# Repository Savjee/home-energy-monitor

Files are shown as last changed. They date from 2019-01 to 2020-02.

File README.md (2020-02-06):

<p align="center">
    <a href="https://github.com/Savjee/home-energy-monitor" rel="noopener">
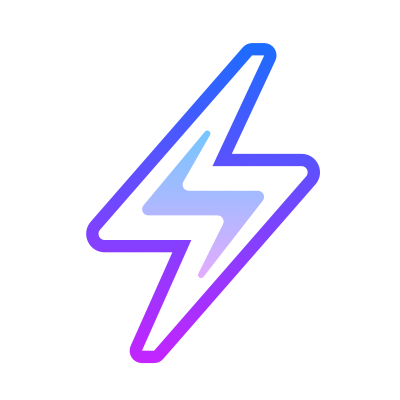
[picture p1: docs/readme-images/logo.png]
Home Energy Monitor
        
    </a>
</p>

<h3 align="center">Home Energy Monitor (v2)</h3>

<div align="center">





**⚠️ This is a work in progress. By no means is this production ready.**
</div>

---

ESP32-based Home Energy Monitor: monitors electricity consumption of your entire house with a single CT sensor.

## Structure

This project consists out of multiple components:

| Folder | Description | Build status | 
| --- | --- | --- |
| `src-app` | Mobile app (Ionic)  | n/a |
| `src-aws` | Serverless AWS backend + GraphQL API |  |
| `src-esp32` | Firmware for the ESP32 (measuring device) |  |

(TODO: add instructions on how to deploy all of this. 😅)

## Video explanation

<div align="center">

IMAGE ALT TEXT HERE (https://www.youtube.com/watch?v=ah3ezprtgmc)

*[https://www.youtube.com/watch?v=ah3ezprtgmc](https://www.youtube.com/watch?v=ah3ezprtgmc)*
</div>

Read my blog post for more instructions: [https://savjee.be/2019/07/Home-Energy-Monitor-ESP32-CT-Sensor-Emonlib/](https://savjee.be/2019/07/Home-Energy-Monitor-ESP32-CT-Sensor-Emonlib/)

## Cloud Architecture

This is the cloud architecture that powers the energy meter and the app:

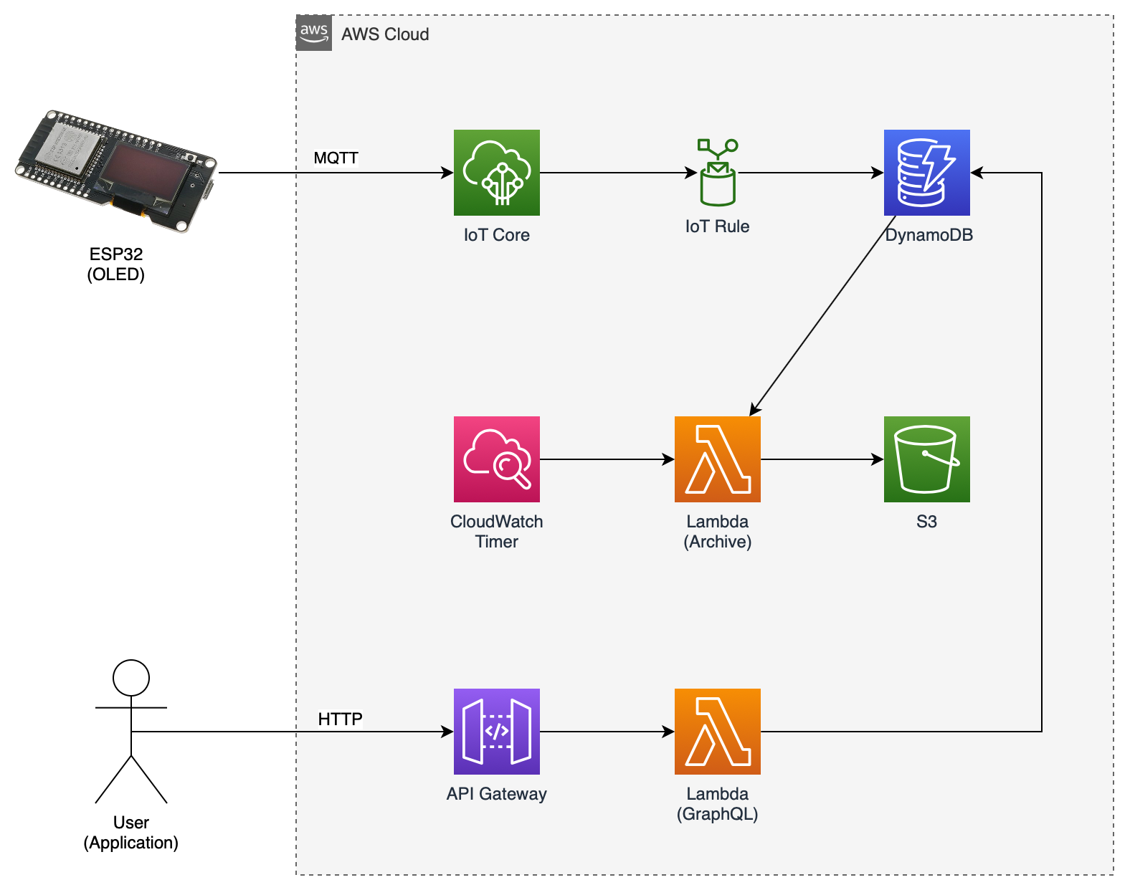
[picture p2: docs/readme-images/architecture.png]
AWS Cloud Architecture


In a nutshell:
* The ESP32 has a MQTT connection with AWS IoT Core
* Every 30 seconds, 30 measurements are sent to AWS
* These measurements are stored in DynamoDB (IoT Rule)
* Once a day, all readings from the previous day are archived to S3
* A GraphQL API (hosted on Lambda) exposes the data stored in DynamoDB

## Screenshots

Web dashboard, built on top of the GraphQL API:

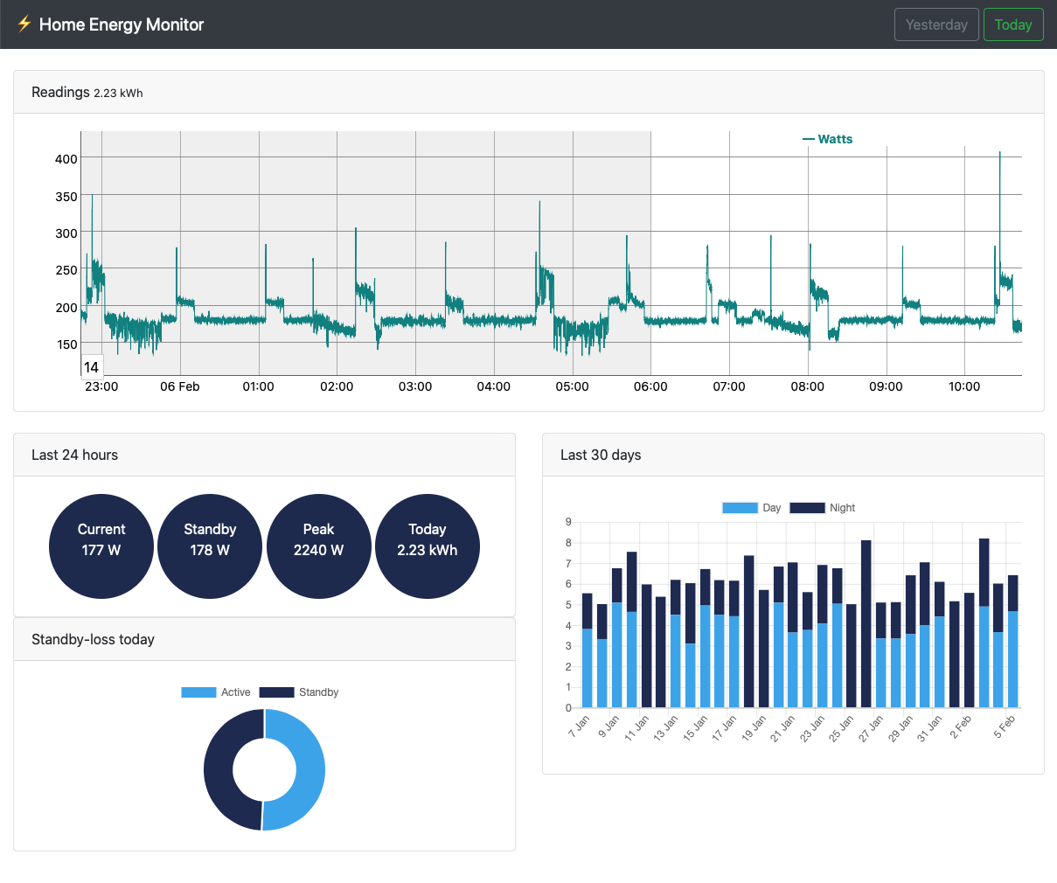
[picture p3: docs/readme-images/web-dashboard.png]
Screenshot Web Dashboard


What is displayed on the ESP32 OLED display:

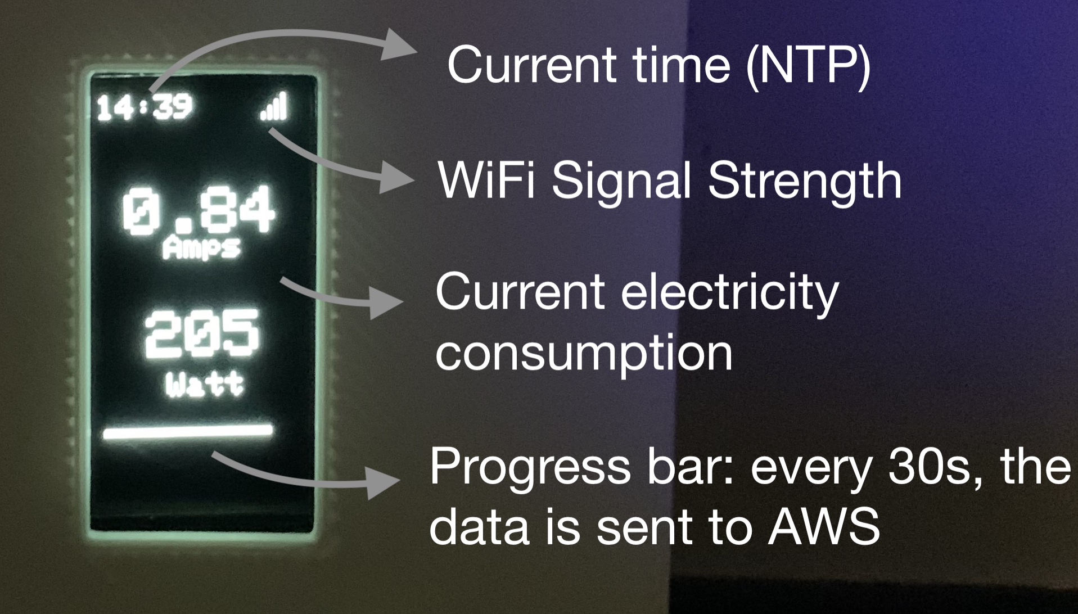
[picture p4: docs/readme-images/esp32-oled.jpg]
Screenshot ESP32 OLED


## DIY Requirements

To build your own Energy Monitor you need the following hardware:

* ESP32
* CT sensor: YHDC SCT-013-030 (30A/1V)
* 10µF capacitor
* 2 resistors (between 10k-470kΩ)

Other requirements:
* AWS Account (Should be able to run in free-tier)
* Install [PlatformIO](https://platformio.org) on your system
* Drivers for your ESP32 board

Read my blog post for more instructions: [https://savjee.be/2019/07/Home-Energy-Monitor-ESP32-CT-Sensor-Emonlib/](https://savjee.be/2019/07/Home-Energy-Monitor-ESP32-CT-Sensor-Emonlib/)

## Contribute

I'm happy to merge in any pull requests. Also feel free to report bugs or feature requests.

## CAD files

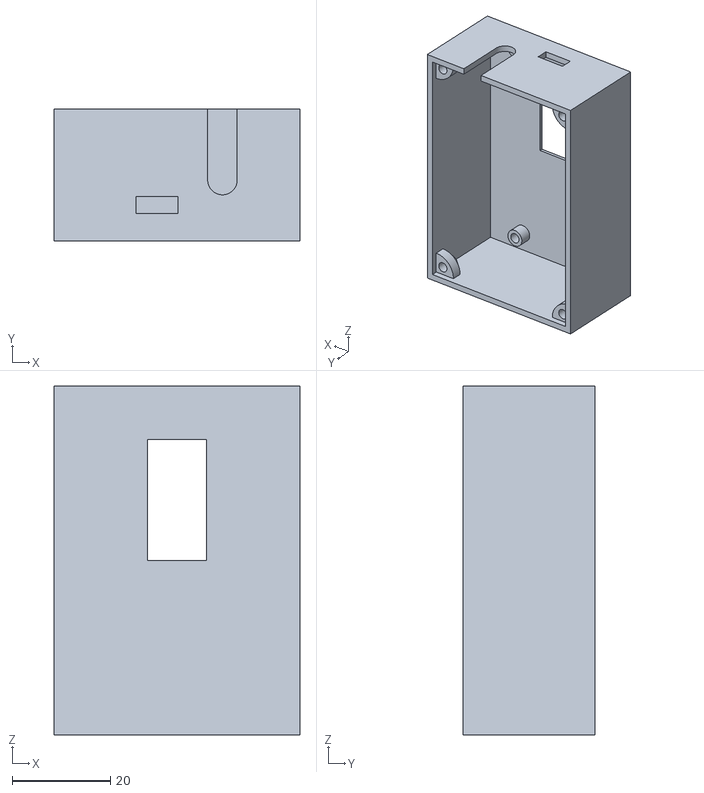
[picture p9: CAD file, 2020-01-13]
3D-designs/01 - Case.stl
50.0 x 26.9 x 71.0

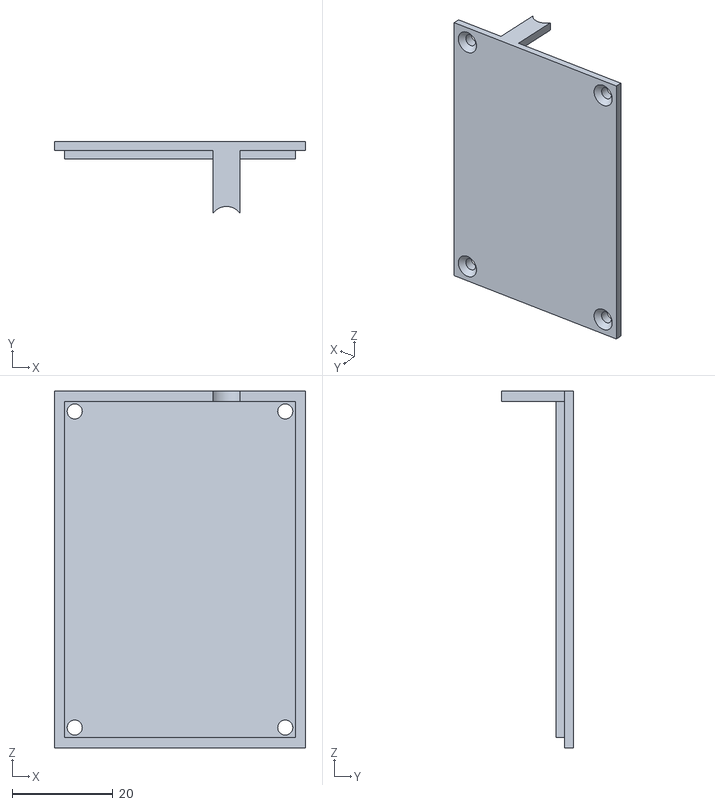
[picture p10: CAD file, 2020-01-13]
3D-designs/02 - Top lid.stl
50.0 x 14.3 x 71.0

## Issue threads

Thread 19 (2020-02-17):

Rebooting on wifi connection screen

CatalanCaptain, 2020-02-17:
After successfully download the firmware on the board, it stucks on wifi connecting page and then reboots forever every second or less.
After running exception decoder, I found that it was due to line #47 on wifi-connection.h task, that shows the status and the IP adress.
After commenting this line everything works fine and pass to the next page, showing power consumption.

Thanks for your awesome work!

Savjee, 2020-02-18:
Interesting.

Could you tell me what versions of PlatformIO & ESP32 framework you're using?

Also: could you test to see if it helps to replace that line with a more simple version (without the F() macro and without my debug serial):

```cpp
Serial.println("[WIFI] Connected: " + WiFi.localIP());
```

CatalanCaptain, 2020-02-18:
Actually running 4.2.0 on platformIO and 1.11.2 on ESP32.
Replacing the line without F() didn't worked. Also, setting `#define DEBUG true` to false, didn't worked either.

Savjee, 2020-02-21:
Really weird, I'm running the exact same versions as you.
For now, I will keep this issue open and see if others are experiencing the same issue.

Have you looked into this in more detail? Any other bug reports mentioning issues with `localIP()` ?

CatalanCaptain, 2020-02-21:
Here is the complete exception decoder output, if you can see anything that I can't

`PC: 0x400014dc
EXCVADDR: 0xce41cbd3

Decoding stack results
0x400d5f59: Print::write(char const*) at C:\Users\My_user\.platformio\packages\framework-arduinoespressif32\cores\esp32/Print.h line 66
0x400d5fcd: Print::println(char const*) at C:\Users\My_user\.platformio\packages\framework-arduinoespressif32\cores\esp32\Print.cpp line 89
0x400d1a76: keepWiFiAlive(void*) at src\tasks/wifi-connection.h line 47
0x400896f9: vPortTaskWrapper at /home/runner/work/esp32-arduino-lib-builder/esp32-arduino-lib-builder/esp-idf/components/freertos/port.c line 143
`

freeesty, 2020-03-15:
having the same issue, 4.2.1 on platformIO and 1.11.2 on ESP32.

Savjee, 2020-03-15:
@freeesty Did it help to remove this line?

`Serial.println("[WIFI] Connected: " + WiFi.localIP());`

freeesty, 2020-03-15:
yes

Savjee, 2020-04-02:
What happens if you replace it with

```
Serial.print("[WIFI] Connected: ");
Serial.println(WiFi.localIP());
```

Really puzzled as to why this gives issues for some, but not for others.

henklietaert, 2020-04-27:
I have the same issue, printing just some words resolves the issue:
` serial_println("Some words");`

henklietaert, 2020-04-27:
The two lines you posted do work for me btw.

TiSiAi, 2020-05-12:
Hello
the macro F(...) include the wifi.localIP() function

replace
serial_println(F("[WIFI] Connected: " + WiFi.localIP()));

with
serial_print(F("[WIFI] Connected: "));
serial_println(WiFi.localIP());

Savjee, 2020-05-28:
Good catch @TiSiAi
I updated the code to fix that ;) https://github.com/Savjee/home-energy-monitor/commit/5c14406d0bf7cac692ed733589ca177845626ab7

Closed 2020-05-28.

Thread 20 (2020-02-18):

Non-zero readings

CatalanCaptain, 2020-02-18:
After setting all up if I plug the CT sensor but with no wire through it, I have a non-zero readings, about 0,1A.
I suspect that this is caused by the difference on the voltage divider resistors, that gives a reference voltage something different than 3,3V/2=1.65V.
It would be interesting to implement some kind of calibration routine to add an offset and get more accurate readings.
Also, when connecting a (theorically) 2000W air heater, readings go around 1800W-1900W. But in this case, I don't know if it's related with the same issue.

Thanks for your time and dedication @Savjee

Savjee, 2020-02-21:
For calibration, you can try playing with `emon1.current` in the main file: https://github.com/Savjee/home-energy-monitor/blob/master/src-esp32/src/main.cpp#L56

The second parameter is a calibration value. More details about it here:
https://learn.openenergymonitor.org/electricity-monitoring/ctac/ct-and-ac-power-adaptor-installation-and-calibration-theory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

As for a calibration routine: that's an interesting idea, but it would require some additional hardware. A button or so to trigger it.

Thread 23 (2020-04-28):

Three phase version

aleonnet, 2020-04-28:
Hi @Savjee great job!
It would be very good if you co

uld include a three phase version. I mean read the current and voltage for the three phases. These would open the possibility for several other applications and house sizes!

Does the EmonLib-esp32 support the three phase calculations?

By the way I will open source my small board to adapt current from the sct-013-000.
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

Savjee, 2020-05-01:
A 3-phase system requires 3 separate CT sensors. This should be easy to achieve because the ESP32 has enough ADC inputs. The only thing required is enough input pins for the sensors ;)

The library doesn't need to be changed. You can create 3 instances of it and have them work together.

Cool! What software are you using to design that PCB? I started mine on EasyEDA but didn't finish it yet. Hard to find components like headphones jacks with correct footprints for EasyEDA. How are you tackling this?

aleonnet, 2020-05-01:
I'm afraid the power factor for each phase would not be calculated correctly, by simply measuring the current without its corresponding voltage. Maybe this can be adjusted by software. What do you think?
I'm using EasyEDA as well and I its really not easy :) to find some good components' footprints. However you can use a pachymeter to check your actual components. For example, I had to adjust the hole size of the stereo jack with it, note that it's larger.

Savjee, 2020-05-09:
Indeed, this is my current problem. I need to add support for a voltage sensor as well. Then the setup would work:

- 3 CT clamps for measuring current
- 1 voltage sensor

Now you can:
- Measure voltage
- Measure current with 3 emonlib instances (while using the actual voltage measurement)

That should give fairly good results. From what I read on OpenEnergyMonitor, it requires an AC-AC power adapter: https://learn.openenergymonitor.org/electricity-monitoring/voltage-sensing/measuring-voltage-with-an-acac-power-adapter

Glad I'm not the only one struggling with EasyEDA. Problem is that I don't have all my components yet. Still waiting on a few from AliEpress...

gieljnssns, 2020-11-30:
@Savjee Any updates on this?

Savjee, 2020-12-02:
I've abandoned the idea of creating a custom PCB. Maybe @aleonnet has finished his?

gieljnssns, 2020-12-02:
@Savjee
I mean the three phase version…
And the support for the voltage sensor.

Savjee, 2020-12-03:
No updates on those fronts, unfortunately.

gieljnssns, 2020-12-17:
@Savjee
> A 3-phase system requires 3 separate CT sensors. This should be easy to achieve because the ESP32 has enough ADC inputs. The only thing required is enough input pins for the sensors ;)

What do you mean with this?
Which pins can be used for ADC? What numbering do I have to use?
https://esp32.com/viewtopic.php?t=13145
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

JamesLeonDufour, 2022-10-11:
I'll be interested to follow up on that one. Here is a good article . http://www.technik-fan.de/index.php/Open_Energy_Monitor_mit_dem_ESP32
That would require an esp 32 not 8266 right ?

Savjee, 2022-10-11:
Yes, the ESP8266 only has 1 ADC channel and you would need 3.
There are two options:
1. Switch to an ESP32 which has 18 channels in total (8 + 10)
2. Use the ESP8266 with an external ADC.

Regardless of which option you choose, an external ADC will always give you better accuracy compared to the built-in ADC.

JamesLeonDufour, 2022-10-11:
Hi Savjee,

Thanks for taking the time to answer, I have been digging quiet a lot on CT clamp and did my first iteration.

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

This is based on your project. Luckily I ordered a SCT-013-030 30a 1v that I assume you are using in your project and if I understand correctly after my reserach doesnt need a burden resistor and seem to make the job a lot easier for everyone (instead of output a ma) ?

So i connected the whole thing, added an Oled screen as you can see and was going to work on the IOT platform, MQTT etc later to transmit data.

Just when I wanted to install it, I realised that I had 3 phases in my house (Belguim), so I continued my digging.

Using the ESP32 option(I have one), the easy way I found is basically replicate the same approach like this example and yours x3. Pretty straight forward. http://www.technik-fan.de/index.php/Open_Energy_Monitor_mit_dem_ESP32.

Other option you are mentionning would be connecting an ADS1115 ? to 3 SCT clamp. But the 0-1V model like the one i have or should i switch back to a 000 series (in ma).

You are mentionning the external ADC (eg: ads1115) would be more accurate, but would I still be able to read each phases independently ? (Could be interesting to monitor which part of the house and plugs consume more).

There is this nice pieces of circuitery as well 4 channel, https://www.mottramlabs.com/esp_products.html but seems a bit of lot of complication with the 2 options listed before.

Lets me know which approach you would follow first ? the easiest ?  ( i assume the ESP8266 + ADS1115 + SCT013-030)

Thanks in advance, this is a very debatted project and seems to be a lot of confusion around the SCT CT clamp different model and the whole interfacing and not really clear project for 3 phases at least.

Best

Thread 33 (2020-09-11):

Standby power consumption

sid548, 2020-09-11:
Hello,
I am going through the project but one thing still I am not able to understand is about the standby power consumption (Always -ON)
. What is the purpose of calculating it and how is it being calculated ?

It would be great if you can give me a hint about that .

Thanks

Savjee, 2020-09-11:
Standby power is the minimum amount of power that your house consumes with appliances that are always on. That's the consumption of: fridges, freezers, standby devices, always plugged-in chargers, etc...

It's being calculated here: https://github.com/Savjee/home-energy-monitor/blob/master/src-aws/functions/graphql/resolvers/stats.js#L20

It basically is the "mode" of the dataset. -> The lowest, most frequently seen value in the set.
That's probably not the correct way of calculating it, but it's close enough.

Hope that helps.

sid548, 2020-09-11:
Thanks a lot

Savjee, 2020-09-11:
Going to close this issue now. But let me know if you have additional questions ;)

Closed 2020-09-11.

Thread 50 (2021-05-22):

Strange behaviour: ESP32 serial monitor shows MQTT msg sent but AWS IOT never receives the same

adukale, 2021-05-22:
Hi
Finally decided to ditch the esp8266 and move to esp32. Made necessory modifications and uploaded code on ESP32.
AWS IOT registers the device, esp32 shows MQTT msg sent in serial monitor but the message is never recived on AWS iot.
No rules executed, nothing. Tried changing the rule, also tried the test menu from AWS IOT to subscribe to "#" i.e. all topics, here also the result is same. No message received.
Also, in thing's activity menu I can see the device was connected but in next 10 seconds the device was disconnecting, this behavior was consistant.

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

The serial monitor shows: AWS publish then AWS Connecting. Is this normal?
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

Savjee, 2021-05-23:
It's not normal that it has to reconnect after sending a message. Looks like a permission issue. When the ESP32's certificate is not allowed to publish to a certain topic, the broker will disconnect you.

Try enabling IoT Core logging and check CloudWatch for additional details:
https://docs.aws.amazon.com/iot/latest/developerguide/configure-logging.html#configure-logging-console

adukale, 2021-05-23:
@Savjee Thank you for the quick response. Checking with this.
Just a query, how should be the certificate & keys in certificates directory? As it is or do I need to enclose the lines in " - " \?

Savjee, 2021-05-23:
As it is, no changes needed.

adukale, 2021-05-23:
@Savjee Thank you for pointing me in the right direction.
Don't know what was the exact issue but I have managed to get the esp32 up and running after fiddling with policies & certificates.
Thank You for the Awesome Project.

Savjee, 2021-05-24:
Nice! AWS IoT Policies are indeed a nightmare to configure correctly. Hard to debug as well.

Closed 2021-05-23.

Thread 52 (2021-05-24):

Readings Screen: The time shown in chart is not in the local timezone.

adukale, 2021-05-24:
The time series in chart x axis is not in the user's timezone / reading's timezone.
Not exactly sure how to fix this because the timestamp returned with readings has correct time but on chart this reflects that the readings are approx 5-5.5 hours before.
Ex: Following screenshot show time & readings from 5AM to 10AM but actually the readings are of time between 11 AM to 4:30 PM.
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

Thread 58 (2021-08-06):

Entity not available for a long time when restarting homeassistant

Pigi-102, 2021-08-06:
When I restart homeassistant for, say , a configuration change or whatever reason the sensor remain in entity not available for quite a long time.
I use mosquitto as broker and all my other sensor ( not "autoconfigured" ) start sending data to broker and get sent to HASS as soon as the HASS itself is up and running.
The only one that remains in "Entity not available" is your ( wonderful ) sensor.
From the mosquitto log I can see that my ESP32 send the message :
1628280703: Received PUBLISH from IoTEnMon (d0, q0, r0, m0, 'homeassistant/sensor/IoTEnMon/state', ... (14 bytes))
but being that HASS does not have a configuration for it, mosqutto don't forward it to HASS.
After some time ( 10 minutes or more ) the ESP32 send the config message:
1628281285: Received PUBLISH from IoTEnMon (d0, q0, r0, m0, 'homeassistant/sensor/IoTEnMon/config', ... (318 bytes))
and from this moment everything works as expected.
Is it possible to have some config item to choice between autoconfig and manually config ?

Savjee, 2021-08-16:
Normally we send a discovery message to Home Assistant every 15 minutes. So it should only take 15minutes at most to get your sensor back in HA.

That FreeRTOS task is defined here:
https://github.com/Savjee/home-energy-monitor/blob/70fd234b305f2d3f8040fb9a9ef743cf9b9b6e74/src-esp32/src/tasks/mqtt-home-assistant.h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

You could run this task more frequently, or trigger it when the MQTT connection is first established.

Not sure if there's another way around this. Maybe define an empty template sensor in HA? Not sure if MQTT could then update it though.

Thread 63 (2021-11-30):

Add multiple sensors

KillahB33, 2021-11-30:
Is this possible to use one of the other inputs on the ESP32 to add another sensor?
I am going to set this up in my main panel and wanted to track a few other things.

Savjee, 2021-12-01:
Yes that's possible by creating more instances of Emonlib.
Unfortunately this is not something I can work on. Happy to accept pull requests though ;)

KillahB33, 2021-12-01:
Deal, I'll see if I can make that happen. Thanks for pointing me in the right direction!

Closed 2021-12-01.

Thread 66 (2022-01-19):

Direct CT Connection

JuandreG, 2022-01-19:
Hello.

Is it possible to connect the SCT013 directly to the ESP32 board and measure amps? You mention that your initial thought was to cut it off and connect the wires directly to the ESP32 board, I would like to do this but I don't know where to connect the wires on the board.

If you could please guide me in connecting these wires on the board directly it would be greatly appreciated.

Regards and awesome project.

Savjee, 2022-01-20:
Hi,

Yes you can connect it directly to the ESP32. It's the exact same wiring. Same pins as you would use for the headphone jack.

Closed 2022-01-20.

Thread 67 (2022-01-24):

Will this work with your code

steveuk23, 2022-01-24:
Hi I love your project and am wondering do you think this ready made board will work with your code.
I prefer the idea of WiFi & MQTT reconnecting that your have on yours.
This guy makes boards on eBay but recommends his code.
Thanks
[https://www.ebay.co.uk/itm/ESP8266-Mains-Current-Sensor-Wemos-Current-transformer-SCT013-100A-50mA-/133077015640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](Ebay)

Savjee, 2022-01-28:
It seems compatible yes. The only things that might change are pin numbers.

Closed 2022-01-28.

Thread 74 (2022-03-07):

Very interresting but can't understand the wiring !

davidmarli, 2022-03-07:
Hi, I'm very interristing on building it, but I don't understand the wiring process ...

Would it be possible to have a complete scheme with resistors, sct-013 plug ... ?

On the blog, it's just 2 pictures and I see nothing ...

Thank you fo your help.

Savjee, 2022-03-08:
The scheme is shown on the V1 blog post:
https://savjee.be/2019/07/Home-Energy-Monitor-ESP32-CT-Sensor-Emonlib/

Closed 2022-03-08.

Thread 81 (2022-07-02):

Getting more Irms decimal points

Ganeshgng, 2022-07-02:
Hi I am Trying to upload sensor data, current and voltage to mysql database. But I am struck. where
Irms value updating only two decimal places e.g X.XX, But I need X.XXXX, How to do it? I tried
1. defining double Irms = emon.Irms/1.0000;
But when I try serial print & lcd print I can get the precision
e.g Serial.print(emon.Irms, 5);

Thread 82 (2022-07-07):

How is the board powered?

vijaygill, 2022-07-07:
Hi,

Interesting project! Thanks for that.

A quick question - how is the voard powered? I don't see any mention of power-supply for ESP32 itself.

Thanks.

Savjee, 2022-07-07:
I used the microUSB connection on my ESP32. Connected to my modem which was nearby.

Closed 2022-07-07.

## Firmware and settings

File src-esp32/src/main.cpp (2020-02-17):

#include <Arduino.h>
#include "EmonLib.h"
#include "WiFi.h"
#include <driver/adc.h>
#include "config/config.h"
#include "config/enums.h"
#include <Wire.h>
#include <Adafruit_GFX.h>
#include <Adafruit_SSD1306.h>

#include "tasks/updateDisplay.h"
#include "tasks/fetch-time-from-ntp.h"
#include "tasks/mqtt-aws.h"
#include "tasks/wifi-connection.h"
#include "tasks/wifi-update-signalstrength.h"
#include "tasks/measure-electricity.h"
#include "tasks/mqtt-home-assistant.h"

Adafruit_SSD1306 display(SCREEN_WIDTH, SCREEN_HEIGHT, &Wire, -1);
DisplayValues gDisplayValues;
EnergyMonitor emon1;

// Place to store local measurements before sending them off to AWS
unsigned short measurements[LOCAL_MEASUREMENTS];
unsigned char measureIndex = 0;

void setup()
{
  #if DEBUG == true
    Serial.begin(115200);
  #endif 

  // Setup the ADC
  adc1_config_channel_atten(ADC1_CHANNEL_0, ADC_ATTEN_DB_11);
  analogReadResolution(ADC_BITS);
  pinMode(ADC_INPUT, INPUT);

  // i2c for the OLED panel
  Wire.begin(5, 4); 

  // Initialize the display
  if(!display.begin(SSD1306_SWITCHCAPVCC, 0x3C, false, false)) {
    serial_println(F("SSD1306 allocation failed"));
    delay(10*1000);
    ESP.restart();
  }

  // Init the display
  display.clearDisplay();
  display.setRotation(3);
  display.setTextSize(1);
  display.setTextColor(WHITE);
  display.setTextWrap(false);

  // Initialize emon library
  emon1.current(ADC_INPUT, 30);

  // ----------------------------------------------------------------
  // TASK: Connect to WiFi & keep the connection alive.
  // ----------------------------------------------------------------
  xTaskCreatePinnedToCore(
    keepWiFiAlive,
    "keepWiFiAlive",  // Task name
    5000,            // Stack size (bytes)
    NULL,             // Parameter
    1,                // Task priority
    NULL,             // Task handle
    ARDUINO_RUNNING_CORE
  );

  // ----------------------------------------------------------------
  // TASK: Connect to AWS & keep the connection alive.
  // ----------------------------------------------------------------
  #if AWS_ENABLED == true
    xTaskCreate(
      keepAWSConnectionAlive,
      "MQTT-AWS",      // Task name
      5000,            // Stack size (bytes)
      NULL,             // Parameter
      5,                // Task priority
      NULL              // Task handle
    );
  #endif

  // ----------------------------------------------------------------
  // TASK: Update the display every second
  //       This is pinned to the same core as Arduino
  //       because it would otherwise corrupt the OLED
  // ----------------------------------------------------------------
  xTaskCreatePinnedToCore(
    updateDisplay,
    "UpdateDisplay",  // Task name
    10000,            // Stack size (bytes)
    NULL,             // Parameter
    3,                // Task priority
    NULL,             // Task handle
    ARDUINO_RUNNING_CORE
  );

  // ----------------------------------------------------------------
  // Task: measure electricity consumption ;)
  // ----------------------------------------------------------------
  xTaskCreate(
    measureElectricity,
    "Measure electricity",  // Task name
    5000,                  // Stack size (bytes)
    NULL,                   // Parameter
    4,                      // Task priority
    NULL                    // Task handle
  );

  // ----------------------------------------------------------------
  // TASK: update time from NTP server.
  // ----------------------------------------------------------------
  #if NTP_TIME_SYNC_ENABLED == true
    xTaskCreate(
      fetchTimeFromNTP,
      "Update NTP time",
      5000,            // Stack size (bytes)
      NULL,             // Parameter
      1,                // Task priority
      NULL              // Task handle
    );
  #endif

  // ----------------------------------------------------------------
  // TASK: update WiFi signal strength
  // ----------------------------------------------------------------
  xTaskCreate(
    updateWiFiSignalStrength,
    "Update WiFi strength",
    1000,             // Stack size (bytes)
    NULL,             // Parameter
    2,                // Task priority
    NULL              // Task handle
  );

  #if HA_ENABLED == true
    xTaskCreate(
      HADiscovery,
      "MQTT-HA Discovery",  // Task name
      5000,                // Stack size (bytes)
      NULL,                 // Parameter
      5,                    // Task priority
      NULL                  // Task handle
    );

    xTaskCreate(
      keepHAConnectionAlive,
      "MQTT-HA Connect",
      5000,
      NULL,
      4,
      NULL
    );
  #endif
}

void loop()
{
  vTaskDelay(10000 / portTICK_PERIOD_MS);
}

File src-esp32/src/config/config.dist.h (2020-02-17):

#ifndef CONFIG
#define CONFIG

/**
 * Set this to false to disable Serial logging
 */
#define DEBUG true

/**
 * The name of this device (as defined in the AWS IOT console).
 * Also used to set the hostname on the network
 */
#define DEVICE_NAME "*****YOUR AWS IOT DEVICE NAME******"

/**
 * ADC input pin that is used to read out the CT sensor
 */
#define ADC_INPUT 36

/**
 * The voltage of your home, used to calculate the wattage.
 * Try setting this as accurately as possible.
 */
#define HOME_VOLTAGE 245.0

/**
 * WiFi credentials
 */
#define WIFI_NETWORK "****** YOUR WIFI NETWORK NAME *******"
#define WIFI_PASSWORD "****** YOUR WIFI PASSWORD *******"

/**
 * Timeout for the WiFi connection. When this is reached,
 * the ESP goes into deep sleep for 30seconds to try and
 * recover.
 */
#define WIFI_TIMEOUT 20000 // 20 seconds

/**
 * How long should we wait after a failed WiFi connection
 * before trying to set one up again.
 */
#define WIFI_RECOVER_TIME_MS 20000 // 20 seconds

/**
 * Dimensions of the OLED display attached to the ESP
 */
#define SCREEN_WIDTH 128
#define SCREEN_HEIGHT 64

/**
 * Force Emonlib to assume a 3.3V supply to the CT sensor
 */
#define emonTxV3 1


/**
 * Local measurements
 */
#define LOCAL_MEASUREMENTS 30


/**
 * The MQTT endpoint of the service we should connect to and receive messages
 * from.
 */
#define AWS_ENABLED true
#define AWS_IOT_ENDPOINT "**** YOUR AWS IOT ENDPOINT ****"
#define AWS_IOT_TOPIC "**** YOUR AWS IOT RULE ARN ****"

#define MQTT_CONNECT_DELAY 200
#define MQTT_CONNECT_TIMEOUT 20000 // 20 seconds


/**
 * Syncing time with an NTP server
 */
#define NTP_TIME_SYNC_ENABLED true
#define NTP_SERVER "pool.ntp.org"
#define NTP_OFFSET_SECONDS 3600
#define NTP_UPDATE_INTERVAL_MS 60000

/**
 * Wether or not you want to enable Home Assistant integration
 */
#define HA_ENABLED false
#define HA_ADDRESS "*** YOUR HOME ASSISTANT IP ADDRESSS ***"
#define HA_PORT 8883
#define HA_USER "*** MQTT USER ***"
#define HA_PASSWORD "*** MQTT PASSWORD ***"

// Check which core Arduino is running on. This is done because updating the 
// display only works from the Arduino core.
#if CONFIG_FREERTOS_UNICORE
#define ARDUINO_RUNNING_CORE 0
#else
#define ARDUINO_RUNNING_CORE 1
#endif

#endif

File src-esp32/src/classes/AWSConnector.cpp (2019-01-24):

#ifndef CLASS_AWSCONNECTOR
#define CLASS_AWSCONNECTOR

#include "../config/config.h"
#include "../config/aws_iot_certificates.h"
#include <WiFiClientSecure.h>
#include <MQTTClient.h>

class AWSConnector
{
  public:
    static AWSConnector* instance;
    WiFiClientSecure net = WiFiClientSecure();
    MQTTClient client = MQTTClient(512);

    /**
     * Called when the ESP32 is in setup mode. Will only be called once
     * when the chip is booting up or wakping up from deep sleep.
     */
    void setup(){
      connect();
    }

    void loop(){
      client.loop();
      delay(10); // Should fix instabilities

      // Make sure the MQTT client is still connected
      if (!client.connected()) {
        connect();
      }
    }

    void sendMessage(String msg){
      client.publish("***REMOVED***", msg);
    }

  private:
    void connect(){
      int retries = 0;

      net.setCACert(AWS_CERT_CA);
      net.setCertificate(AWS_CERT_CRT);
      net.setPrivateKey(AWS_CERT_PRIVATE);

      // Connect to the MQTT broker
      client.begin(AWS_IOT_ENDPOINT, 8883, net);

      // Try to connect to AWS and count how many times we retried.
      // After reaching the maximum we should stop!
      Serial.print("Connecting to AWS IOT...");
      while (!client.connect("xd-home-energy-monitor-1") && retries < AWS_MAX_RECONNECT_TRIES) {
        Serial.print(".");
        delay(AWS_RECONNECT_DELAY);
        retries++;
      }

      // Make sure that we did indeed successfully connect to the MQTT broker
      // If not we just end the function and wait for the next loop.
      if(!client.connected()){
        Serial.println(" Timeout!");
        return;
      }

      // If we land here, we have successfully connected to AWS!
      // And we can subscribe to topics and send messages.
      Serial.println("Connected!");
    }
};

#endif

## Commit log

2019-01-06 Fixing night tarif highlighting when it’s still ongoing
2019-01-07 Initial commit of the device code
2019-01-14 Adding “Today” and “Yesterday” button to zoom in on those
2019-01-16 Initial commit of the ESP32 code (not finished porting over to platformio)
2019-01-21 Added a policy for IoT devices so they’re allowed to publish to the rule
2019-01-24 Use the clientId() to insert items into DYnamoDB
2019-01-24 Final code for ESP32!
2019-01-25 Putting our one deviceName in a config file
2019-02-22 Remove the old Arduino ino project
2019-02-22 App: remove the more menu. Don’t have anything for it now
2019-08-26 Reworking Arduino code for ESP32 + OLED
    [main.cpp]
2020-01-03 Change device name (this is v2)
2020-01-03 Set correct home voltage
2020-01-03 Fix deepsleep: should only be for 30 seconds, not 30 minutes!
    [main.cpp]
2020-01-04 Use my own emonlib fork to enable 12-bit ADC on ESP32
2020-01-04 Backend: go with energy-monitor-2 (TODO: add full support for multiple devices)
2020-01-06 Added 3D case design
    [01 - Case.stl, 02 - Top lid.stl]
2020-02-05 Add GitHub action to compile ESP32 firmware with Platformio
2020-02-05 Firmware: fixing CI and config.h
    [config.dist.h]
2020-02-05 Firmware: use println
2020-02-06 Backend: flexible S3 bucket name + dynamoDB
2020-02-06 ESP32: add preliminary Home Assistant support (not working)
    [main.cpp]
2020-02-11 ESP32: tweaking the stack size of tasks
2020-02-11 ESP32: Fixing Home Assistant integration! Yay!
2020-02-11 ESP32: Don't go to deep sleep when WiFi can't connect
2020-02-12 Don't go to deepsleep to recover. Instead, reboot ESP!
    [main.cpp]
2020-02-12 Disable debug mode on ESP32
2020-02-14 ESP32: Removing unnecessary spaces in JSON
2020-02-14 ESP32: removing F() macro for MQTT HA (to see if it improves stability)
2020-02-14 ESP32: don't use String in Home Assistant MQTT
2021-03-06 Update serverless.yml to update AWS IOT ARN in Rule SQL
    Updated sql in AWS IOT RULE to user ARN. This resolves error where rule was able to insert data in Dynamo DB

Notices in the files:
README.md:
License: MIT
